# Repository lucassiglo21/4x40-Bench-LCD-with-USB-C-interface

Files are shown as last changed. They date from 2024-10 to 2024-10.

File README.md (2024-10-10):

# 4x40 Bench LCD with USB-C interface for LCD Smartie
This is a 40x4 character LCD controller and a machined aluminum case with an USB-C interface based around a PIC18F2550
It's intended to work with LCDSmartie

Based on the original work by caesar on the LCDSmartie forums: https://lcdsmartie.org/forums/viewtopic.php?p=22548

Im providing the following:

1- 3D model in solidworks, STEP files and blueprints for machining the case

2- PCB for the interface with USB-C horizontal, USB-C vertical connectors and 0.1in header

3- Source code for the PIC18F2550 with brightness and contrast control. The project is built for MPLAB X IDE v6.20 with the C18 compiler 

Everything should work with LCD and VFD displays.

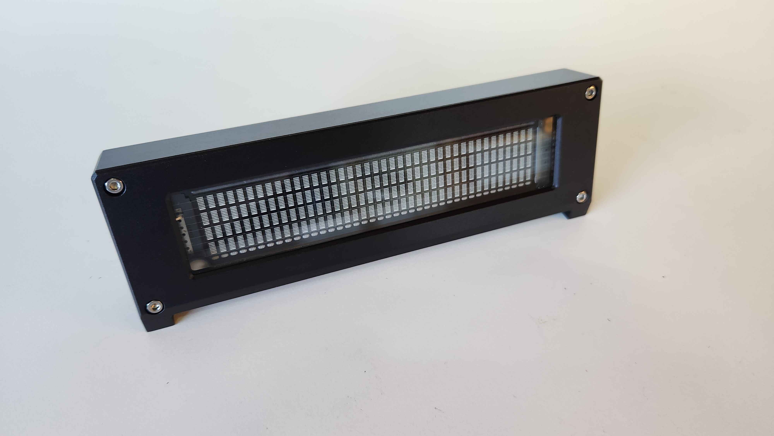
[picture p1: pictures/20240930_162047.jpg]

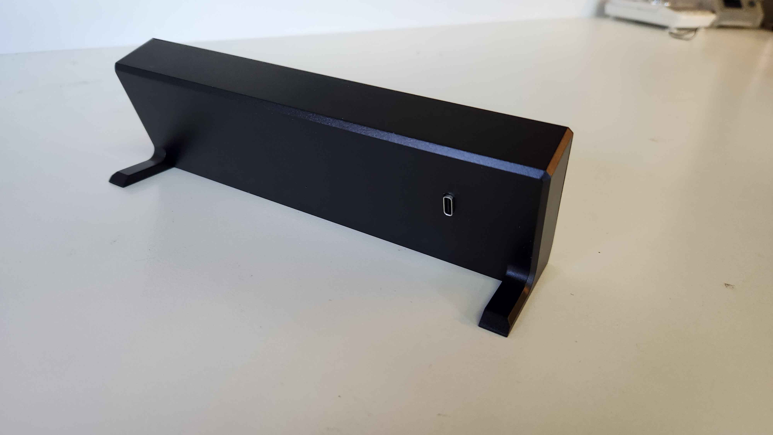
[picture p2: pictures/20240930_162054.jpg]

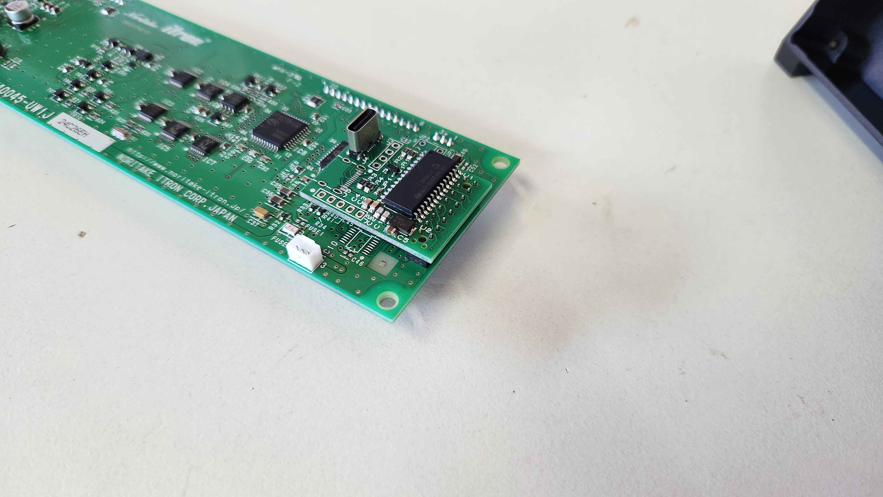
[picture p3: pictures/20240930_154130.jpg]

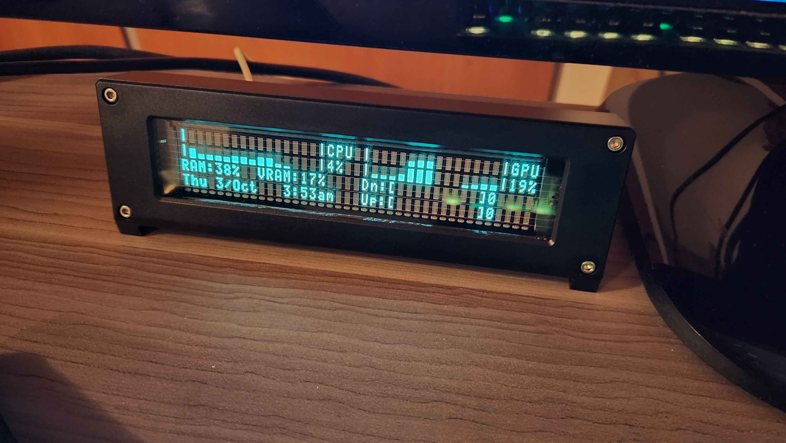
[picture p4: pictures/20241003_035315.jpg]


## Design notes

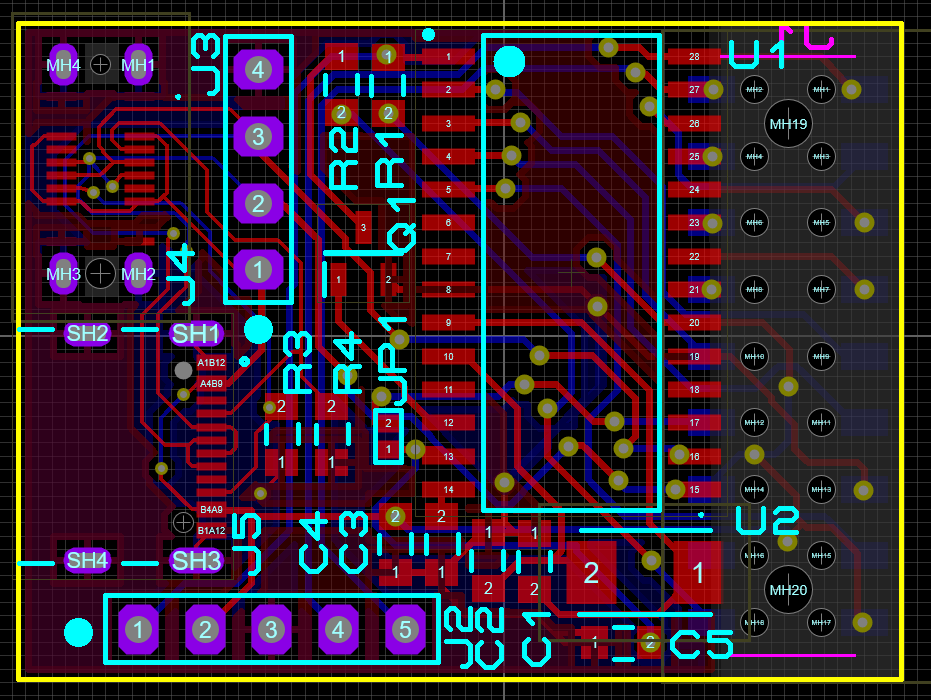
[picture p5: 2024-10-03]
PCB/board2.png

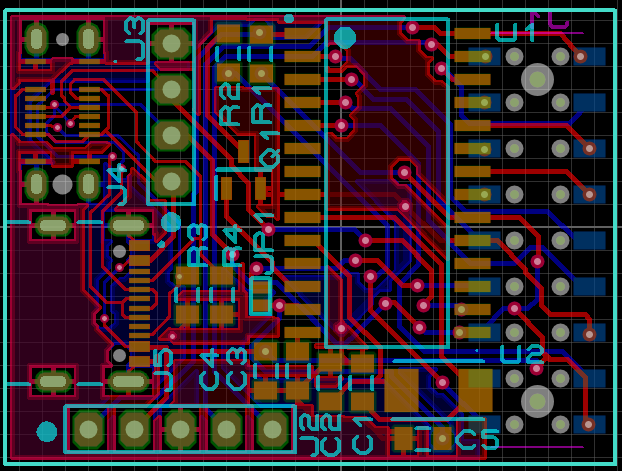
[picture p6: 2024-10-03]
PCB/gerber.png

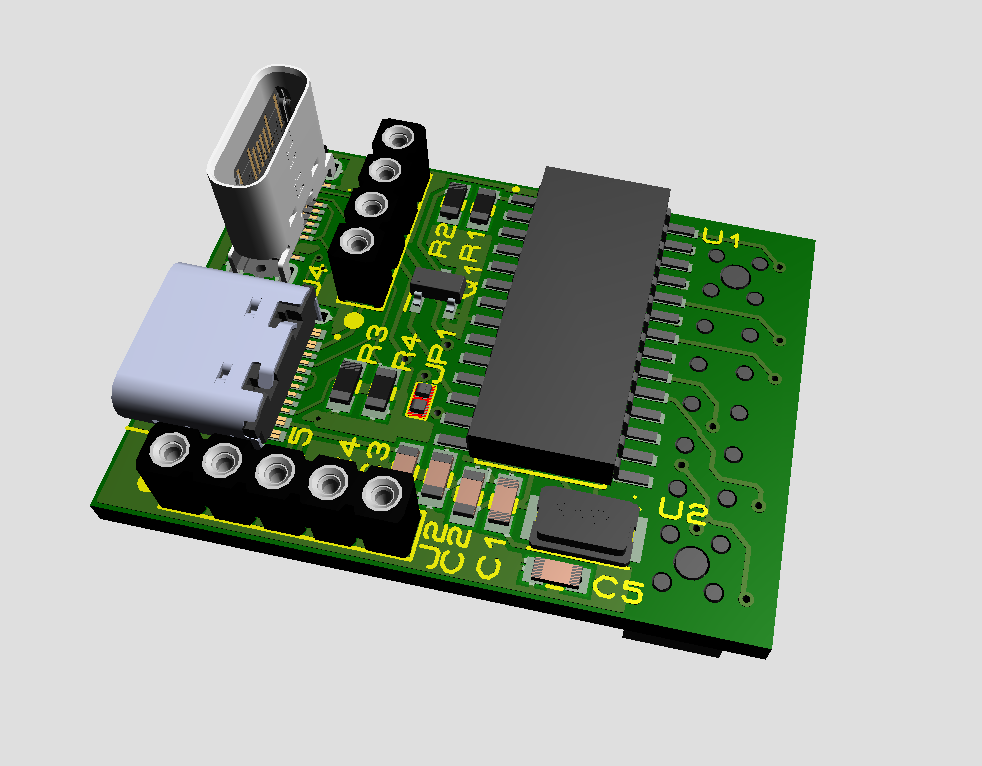
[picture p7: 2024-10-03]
PCB/board.png

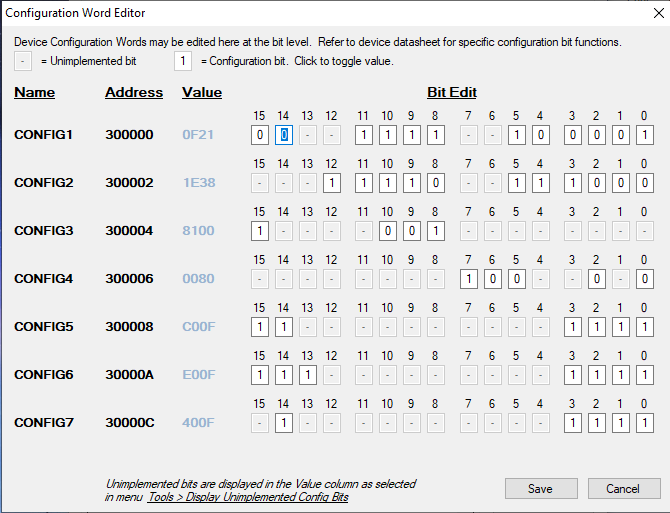
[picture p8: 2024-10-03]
pic18F2550 code/fuses 8mhz xtal.png

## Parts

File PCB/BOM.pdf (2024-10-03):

## Bill Of Materials for pic backpack

Design Title | pic backpack

### Author Document Number Revision

Design Created | 06 September 2024

### Design Last Modified 07 September 2024 Total Parts In Design 18

0 Modules
Quantity | References | Value | Stock Code | Unit Cost
Sub-totals: | | | | £0.00
5 Capacitors
Quantity | References | Value | Stock Code | Unit Cost
2 | C1-C2 | 18pF | Digikey 311-1102-1-ND
2 | C3-C4 | 100n | Farnell 499-687
1 | C5 | 1u | Farnell 317-640
Sub-totals: | | | | £0.00
4 Resistors
Quantity | References | Value | Stock Code | Unit Cost
1 | R1 | 10k | 72-0869
1 | R2 | 33R | 72-0524
2 | R3-R4 | 5k1 | 72-0845
Sub-totals: | | | | £0.00
2 Integrated Circuits
Quantity | References | Value | Stock Code | Unit Cost
1 | U1 | PIC18F2550
1 | U2 | ABM3-8
Sub-totals: | | | | £0.00
1 Transistors
Quantity | References | Value | Stock Code | Unit Cost
1 | Q1 | AO3400-SOT23
Sub-totals: | | | | £0.00
0 Diodes
Quantity | References | Value | Stock Code | Unit Cost
Sub-totals: | | | | £0.00
6 Miscellaneous
Quantity | References | Value | Stock Code | Unit Cost
1 | J1 | M20-7810945
1 | J2 | CONN-SIL5
1 | J3 | CONN-SIL4
1 | J4 | USB4145-03-0070-C
1 | J5 | USB4105GFA
1 | JP1 | JUMPER
Sub-totals: | | | | £0.00
Totals: | | | | £0.00
| | | | 07 September 2024 01:35:26 PM

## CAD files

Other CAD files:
Case 3d model/R2.sldasm
Case 3d model/Open CASCADE STEP translator 6.8 1.2.1.sldasm
Case 3d model/Open CASCADE STEP translator 6.8 1.3.1.sldasm
Case 3d model/=_[0_1_1_4].sldasm
Case 3d model/J1.sldasm
Case 3d model/R4.sldasm
Case 3d model/R1.sldasm
Case 3d model/Imported.sldasm
Case 3d model/U1.sldasm
Case 3d model/C3.sldasm
Case 3d model/C1.sldasm
Case 3d model/Body_1_5.sldasm
Case 3d model/U2.sldasm
Case 3d model/Open CASCADE STEP translator 6.8 1.4.1.sldasm
Case 3d model/J5.sldasm
Case 3d model/JP1.sldasm
Case 3d model/Open CASCADE STEP translator 6.8 1.15.1.sldasm
Case 3d model/J4.sldasm
Case 3d model/61301821121_Download_IGS_61301821121_rev1.SLDASM
Case 3d model/=_[0_1_1_2].sldprt
Case 3d model/=_[0_1_1_2]_2.sldprt
Case 3d model/=_[0_1_1_3].sldasm
Case 3d model/=_[0_1_1_3].sldprt
Case 3d model/=_[0_1_1_3]_2.sldasm
Case 3d model/=_[0_1_1_4].sldprt
Case 3d model/=_[0_1_1_4]_2.sldprt
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

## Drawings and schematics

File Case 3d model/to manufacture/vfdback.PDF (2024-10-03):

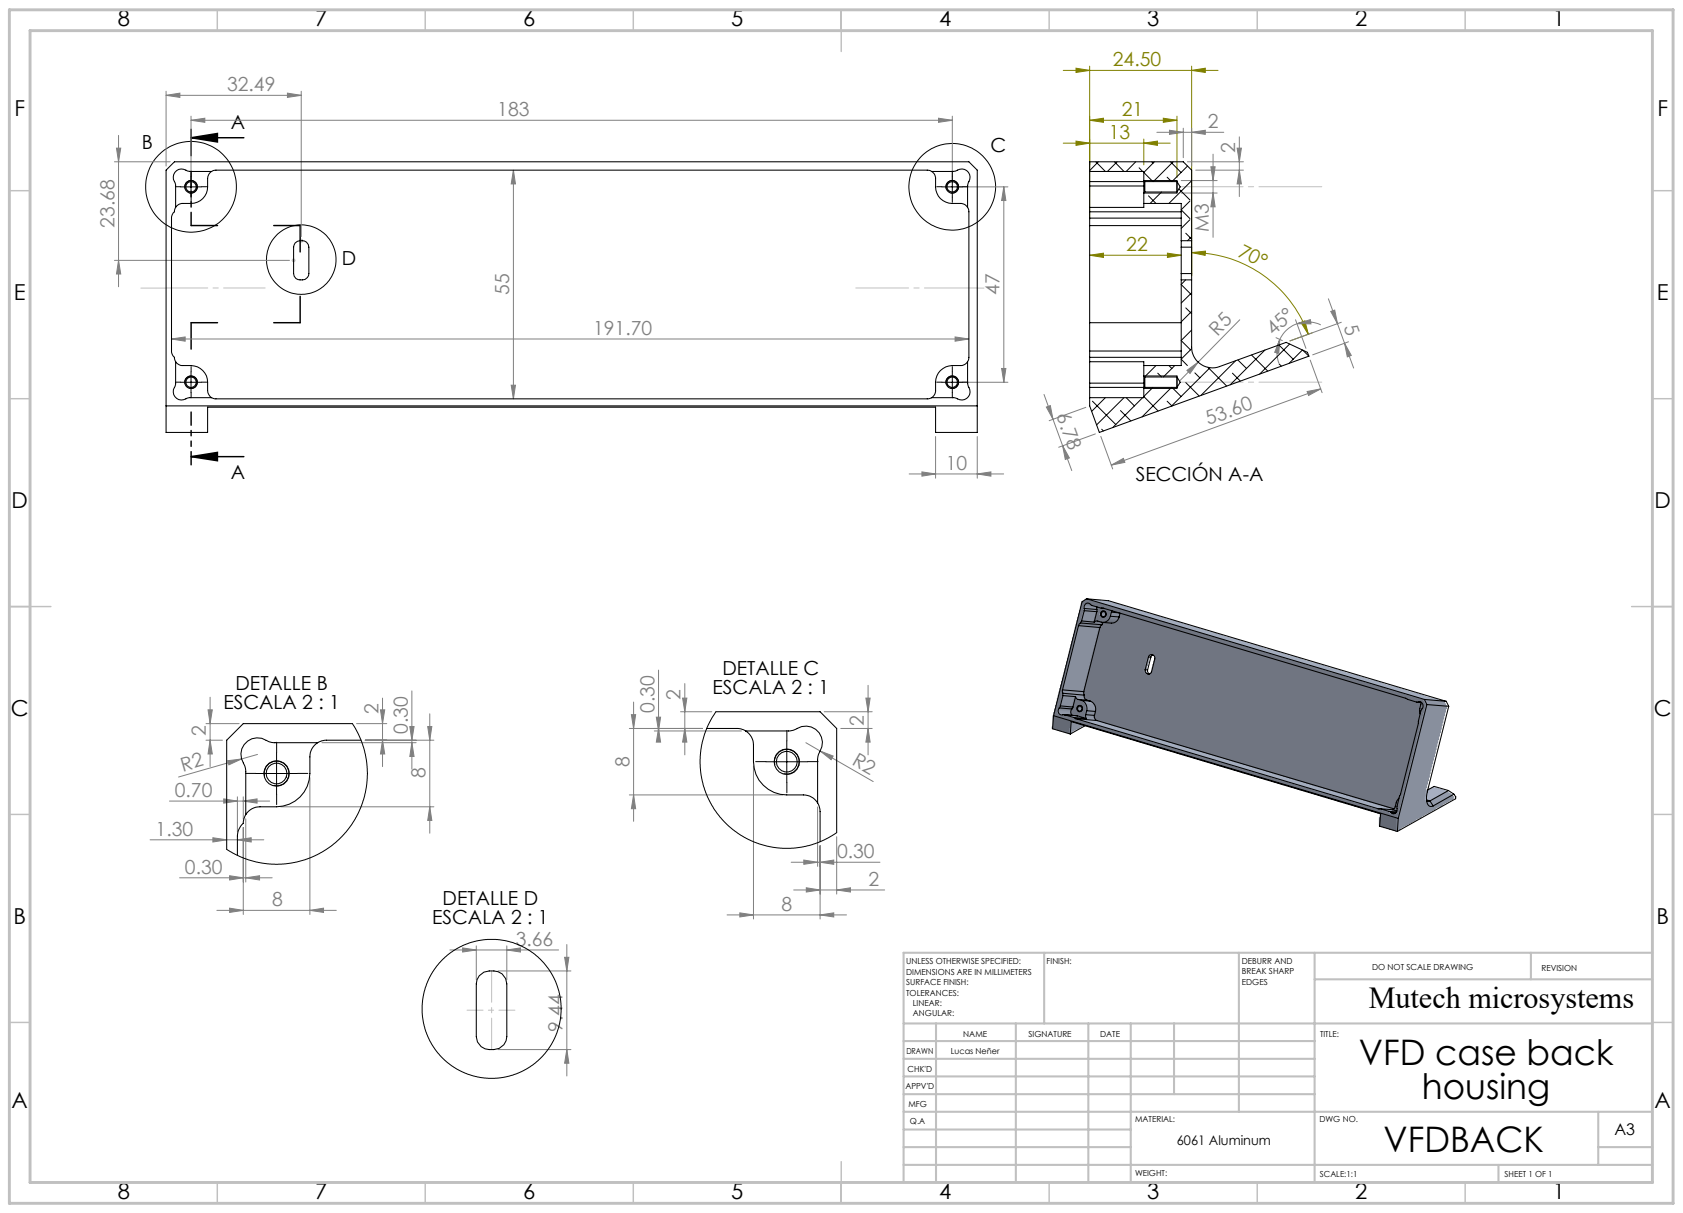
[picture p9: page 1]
SECCIÓN A-A; DETALLE B ESCALA 2 : 1; DETALLE C ESCALA 2 : 1; DETALLE D ESCALA 2 : 1; FINISH:; DEBURR AND; BREAK SHARP; DO NOT SCALE DRAWING; REVISION; SCALE:1:1; SHEET 1 OF 1; Mutech microsystems

UNLESS OTHERWISE SPECIFIED:
DIMENSIONS ARE IN MILLIMETERS
SURFACE FINISH:
TOLERANCES:
LINEAR:
ANGULAR:

NAME | SIGNATURE | DATE | | | | TITLE: VFD case back

DRAWN | Lucas Neñer
CHK'D
APPV'D
MFG
Q.A | | | | MATERIAL: | DWG NO. VFDBACK | A3 6061 Aluminum

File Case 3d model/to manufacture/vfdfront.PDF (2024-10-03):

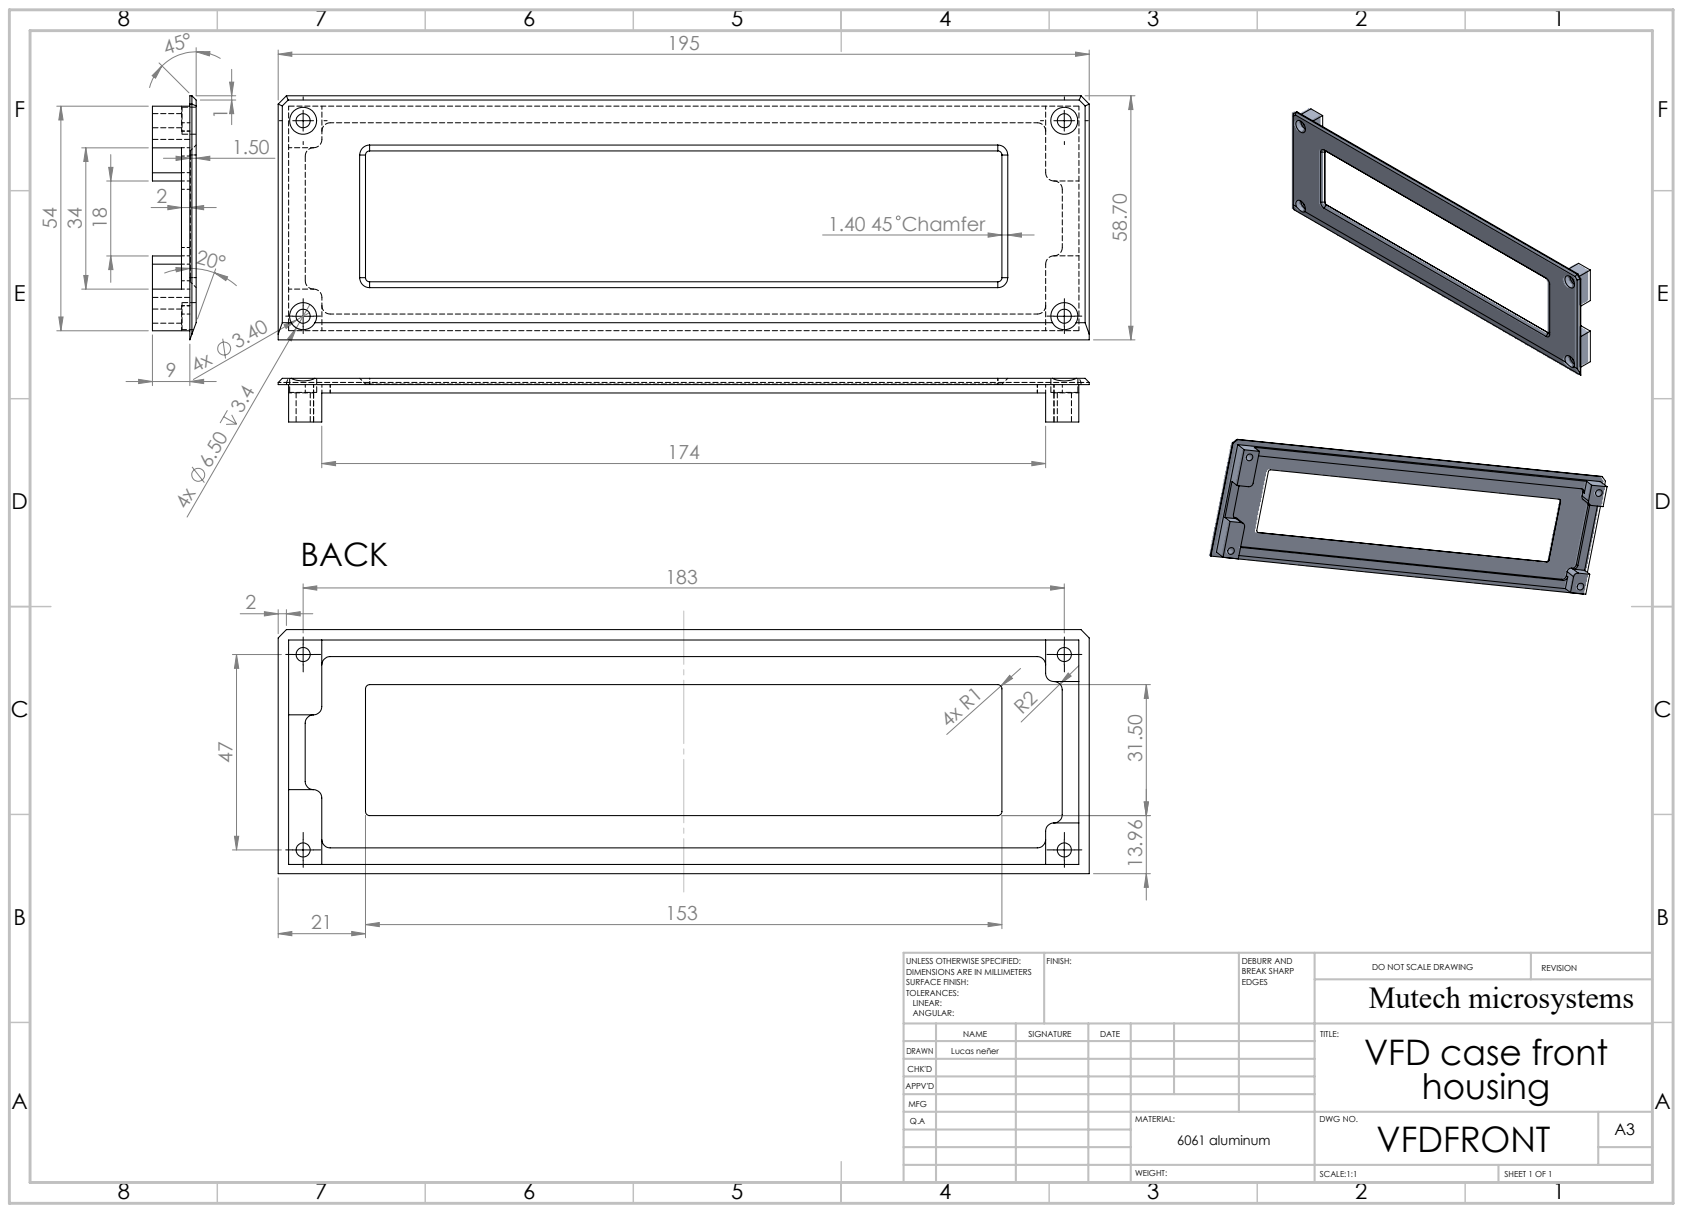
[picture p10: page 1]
1.40 45 Chamfer; FINISH:; DEBURR AND; BREAK SHARP; DO NOT SCALE DRAWING; REVISION; SCALE:1:1; SHEET 1 OF 1; Mutech microsystems

UNLESS OTHERWISE SPECIFIED:
DIMENSIONS ARE IN MILLIMETERS
SURFACE FINISH:
TOLERANCES:
LINEAR:
ANGULAR:

NAME | SIGNATURE | DATE | | | | TITLE: VFD case front housing

DRAWN | Lucas neñer
CHK'D
APPV'D
MFG
Q.A | | | | MATERIAL: | DWG NO. VFDFRONT | A3 6061 aluminum

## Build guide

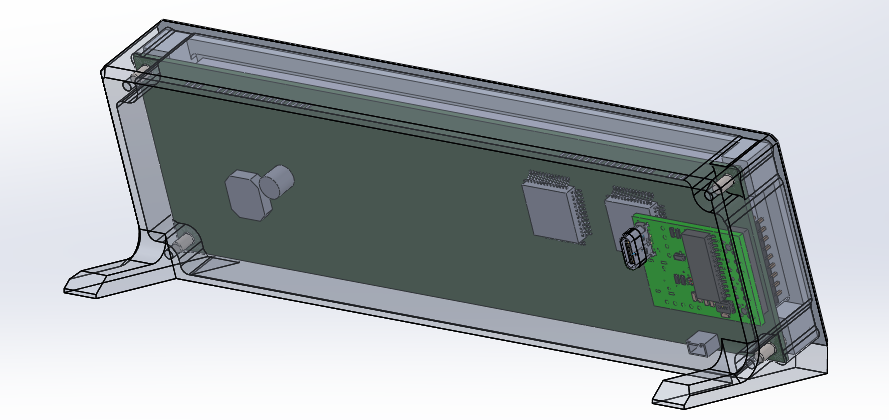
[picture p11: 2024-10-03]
Case 3d model/to manufacture/Untitled.png

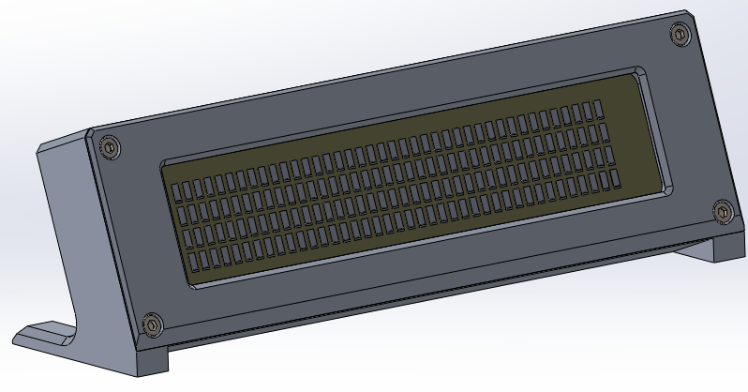
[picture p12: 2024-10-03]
Case 3d model/to manufacture/Untitled2.png

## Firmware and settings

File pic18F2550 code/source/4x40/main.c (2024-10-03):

/*********************************************************************
 *
 *                Microchip USB C18 Firmware Version 1.0
 *
 *********************************************************************
 * FileName:        main.c
 * Dependencies:    See INCLUDES section below
 * Processor:       PIC18
 * Compiler:        C18 2.30.01+
 * Company:         Microchip Technology, Inc.
 *
 * Software License Agreement
 *
 * The software supplied herewith by Microchip Technology Incorporated
 * (the “Company”) for its PICmicro® Microcontroller is intended and
 * supplied to you, the Company’s customer, for use solely and
 * exclusively on Microchip PICmicro Microcontroller products. The
 * software is owned by the Company and/or its supplier, and is
 * protected under applicable copyright laws. All rights are reserved.
 * Any use in violation of the foregoing restrictions may subject the
 * user to criminal sanctions under applicable laws, as well as to
 * civil liability for the breach of the terms and conditions of this
 * license.
 *
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
 * Author               Date        Comment
 *~~~~~~~~~~~~~~~~~~~~~~~~~~~~~~~~~~~~~~~~~~~~~~~~~~~~~~~~~~~~~~~~~~~~
 * Rawin Rojvanit       11/19/04    Original.
 ********************************************************************/

/** I N C L U D E S **********************************************************/
#include <p18f2550.h>
#include "system\typedefs.h"                        // Required
#include "system\usb\usb.h"                         // Required
#include "io_cfg.h"                                 // Required

#include "system\usb\usb_compile_time_validation.h" // Optional
#include "user\user.h"                              // Modifiable

//** FUSES *****************************************************************

#pragma config PLLDIV = 2
#pragma config CPUDIV=OSC1_PLL2
#pragma config USBDIV = 2
#pragma config FOSC = HSPLL_HS
#pragma config FCMEN = OFF
#pragma config IESO = OFF
#pragma config PWRT = ON
#pragma config BOR = OFF
#pragma config BORV = 3
#pragma config VREGEN = ON
#pragma config WDT = OFF
#pragma config WDTPS = 32768
#pragma config MCLRE = ON
#pragma config LPT1OSC = OFF
#pragma config PBADEN = OFF
#pragma config CCP2MX = ON
#pragma config STVREN = OFF
#pragma config LVP = OFF
#pragma config XINST = OFF
#pragma config DEBUG = OFF
#pragma config CP0 = OFF
#pragma config CP1 = OFF
#pragma config CP2 = OFF
#pragma config CP3 = OFF
#pragma config CPB = OFF
#pragma config CPD = OFF
#pragma config WRT0 = OFF
#pragma config WRT1 = OFF
#pragma config WRT2 = OFF
#pragma config WRT3 = OFF
#pragma config WRTB = OFF
#pragma config WRTC = OFF
#pragma config WRTD = OFF
#pragma config EBTR0 = OFF
#pragma config EBTR1 = OFF
#pragma config EBTR2 = OFF
#pragma config EBTR3 = OFF
#pragma config EBTRB=OFF


/** V A R I A B L E S ********************************************************/
#pragma udata

/** P R I V A T E  P R O T O T Y P E S ***************************************/
static void InitializeSystem(void);
void USBTasks(void);

/** V E C T O R  R E M A P P I N G *******************************************/
//
//extern void _startup (void);        // See c018i.c in your C18 compiler dir
//#pragma code _RESET_INTERRUPT_VECTOR = 0x000800
//void _reset (void)
//{
//    _asm goto _startup _endasm
//}
//#pragma code

/** D E C L A R A T I O N S **************************************************/
#pragma code
/******************************************************************************
 * Function:        void main(void)
 *
 * PreCondition:    None
 *
 * Input:           None
 *
 * Output:          None
 *
 * Side Effects:    None
 *
 * Overview:        Main program entry point.
 *
 * Note:            None
 *****************************************************************************/
void main(void)
{
    InitializeSystem();
    while(1)
    {
        USBTasks();         // USB Tasks
        ProcessIO();        // See user\user.c & .h
    }//end while
}//end main

/******************************************************************************
 * Function:        static void InitializeSystem(void)
 *
 * PreCondition:    None
 *
 * Input:           None
 *
 * Output:          None
 *
 * Side Effects:    None
 *
 * Overview:        InitializeSystem is a centralize initialization routine.
 *                  All required USB initialization routines are called from
 *                  here.
 *
 *                  User application initialization routine should also be
 *                  called from here.                  
 *
 * Note:            None
 *****************************************************************************/
static void InitializeSystem(void)
{
    ADCON1 |= 0x0F;                 // Default all pins to digital
    
    #if defined(USE_USB_BUS_SENSE_IO)
    tris_usb_bus_sense = INPUT_PIN; // See io_cfg.h
    #endif
    
    #if defined(USE_SELF_POWER_SENSE_IO)
    tris_self_power = INPUT_PIN;
    #endif
    
    mInitializeUSBDriver();         // See usbdrv.h
    
    UserInit();                     // See user.c & .h

}//end InitializeSystem

/******************************************************************************
 * Function:        void USBTasks(void)
 *
 * PreCondition:    InitializeSystem has been called.
 *
 * Input:           None
 *
 * Output:          None
 *
 * Side Effects:    None
 *
 * Overview:        Service loop for USB tasks.
 *
 * Note:            None
 *****************************************************************************/
void USBTasks(void)
{
    /*
     * Servicing Hardware
     */
    USBCheckBusStatus();                    // Must use polling method
//    if(UCFGbits.UTEYE!=1)
        USBDriverService();                 // Interrupt or polling method
    
//    #if defined(USB_USE_CDC)
    CDCTxService();
//    #endif

}// end USBTasks

/** EOF main.c ***************************************************************/

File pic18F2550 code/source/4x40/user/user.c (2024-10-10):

/*********************************************************************
 *
 *                Microchip USB C18 Firmware Version 1.0
 *
 *********************************************************************
 * FileName:        user.c
 * Dependencies:    See INCLUDES section below
 * Processor:       PIC18
 * Compiler:        C18 2.30.01+
 * Company:         Microchip Technology, Inc.
 *
 * Software License Agreement
 *
 * The software supplied herewith by Microchip Technology Incorporated
 * (the ?Company?) for its PICmicro® Microcontroller is intended and
 * supplied to you, the Company?s customer, for use solely and
 * exclusively on Microchip PICmicro Microcontroller products. The
 * software is owned by the Company and/or its supplier, and is
 * protected under applicable copyright laws. All rights are reserved.
 * Any use in violation of the foregoing restrictions may subject the
 * user to criminal sanctions under applicable laws, as well as to
 * civil liability for the breach of the terms and conditions of this
 * license.
 *
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
 * Author               Date        Comment
 *~~~~~~~~~~~~~~~~~~~~~~~~~~~~~~~~~~~~~~~~~~~~~~~~~~~~~~~~~~~~~~~~~~~~
 * Rawin Rojvanit       11/19/04    Original.
 ********************************************************************/

/******************************************************************************
 * CDC RS-232 Emulation Tutorial Instructions:
 ******************************************************************************
 * Refer to Application Note AN956 for explanation of the CDC class.
 * 
 * First take a look at Exercise_Example() and study how functions are called.
 * 
 * There are five exercises, each one has a solution in the CDC\user\solutions.
 * Scroll down and look for Exercise_01,_02,_03,_04, and _05.
 * Instructions on what to do is inside each function.
 * 
 *****************************************************************************/

/** I N C L U D E S **********************************************************/
#include <p18f2550.h>
#include "system\typedefs.h"
#include "system\usb\usb.h"

#include "io_cfg.h"             // I/O pin mapping
#include "user\user.h"


/** V A R I A B L E S ********************************************************/
#pragma udata

char input_buffer_pointer;
char input_buffer_size;
char input_buffer_char;

char input_buffer[64];
char output_buffer[64];

//extern
//char cdc_rx_len;

char i;

char savecontroller;
char controller;
char transient;
char LCDready;
char LCDsetupstate;
char nextchar;
char onebyte;
char customdone;
char col;
char row;
char custom[9];
char backlight;
char contrast;
char position;

char getnextbyte();


/** P R I V A T E  P R O T O T Y P E S ***************************************/

char getnextbyte(void);
char getnewbuffer(void);
char getsUSBUSART(char *buffer, char len);

void whatcommand(void);
void setupLCD(void);
void sortCMD(void);
void LCDw(char onebyte);
void LCDch(char onebyte);
void LCDposition(char col, char row);


char LCDbusy(void);
char LCDcustom(void);
char start[27] = "            **LCD SMARTIE**";

/** D E C L A R A T I O N S **************************************************/
#pragma code
void UserInit(void)
{
	TRISEN1=0;
	TRISEN2=0;
	TRISRS=0;
	TRISRW=0;
	TRISBL=0;
	TRISCT=0;
	TRISDATA=0;
	EN1=0;
	EN2=0;
	RS=0;
	RW=0;
	BL=0;
	CT=0;
	DATA=0;
	ADCON1=0x0F; //ALL DIGITAL
	CMCON=0x07;  //PORTA COMPARATORS OFF

	//SETUP HARDWARE PWM
	T2CON=0b0000111;
	TMR2=0;
	PR2=0xFF;
	CCP1CON=0b001100; //SET PWM lsb TO 11 AND CCP1 AS PWM
	CCP2CON=0b001100; //FOR CCP2
	CCPR1L=0b00000000; //10-BIT RESOLUTION
	CCPR2L=0b11111111;
	//END SETUP PWM

	customdone = 9;
	nextchar = 0;
	savecontroller = 0;
	controller = 3;
	backlight = 128;
	LCDsetupstate = 0;
	LCDready = 0;
}

/******************************************************************************
 * Overview:        This function is a place holder for other user routines.
 *                  It is a mixture of both USB and non-USB tasks.
 *****************************************************************************/
void ProcessIO(void)
{   
    if ((usb_device_state < CONFIGURED_STATE)||(UCONbits.SUSPND==1)){return;}
	if (!LCDready){setupLCD(); return;}
	if (LCDbusy()){return;}
	if (!LCDcustom()){return;}
	if (getnextbyte()){sortCMD();}
	return;
}
//end ProcessIO


void setupLCD(void)
{
	switch(LCDsetupstate)
	{
		case 0 : LCDsetupstate++; break;
        
		//config 8 bit mode, 2 line, display on
		case 1 : LCDw(0b00111100); LCDsetupstate++; break;
        // set VFD brightness
        case 2 : if(!LCDbusy()){LCDch(0b00000000); LCDsetupstate++;} break;
		//config cursor shifts right
		case 3 : if(!LCDbusy()){LCDw(0b00010100); LCDsetupstate++;} break;

		//config display on, cursor off, blinking off
		case 4 : if(!LCDbusy()){LCDw(0b00001100); LCDsetupstate++;} break;

		// clear display
		case 5 : if(!LCDbusy()){LCDw(0b00000001); LCDsetupstate++;} break;

		// return home
		case 6 : if(!LCDbusy()){LCDw(0b00000010); LCDsetupstate++;} break;

		// write my data
		case 7 : if(!LCDbusy()){LCDch(77); LCDsetupstate++;} break;
		case 8 : if(!LCDbusy()){LCDch(97); LCDsetupstate++;} break;
		case 9 : if(!LCDbusy()){LCDch(100); LCDsetupstate++;} break;
		case 10 : if(!LCDbusy()){LCDch(68); LCDsetupstate++;} break;
		case 11 : if(!LCDbusy()){LCDch(79); LCDsetupstate++;} break;
		case 12 : if(!LCDbusy()){LCDch(67); LCDsetupstate++;} break;
        
		//signal LCDisSetup
		case 13 : 
            input_buffer_pointer=0;
            input_buffer_size=0; 
            clear_input_buffer(); 
            LCDready=1; 
            controller=1; 
            break;
	}
}
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
